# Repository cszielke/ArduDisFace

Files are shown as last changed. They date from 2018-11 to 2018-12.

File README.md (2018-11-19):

# ArduDisFace
An Arduino compatible display interface with I2C, SPI and TTY/RS232 for Arduino and Raspberry PI
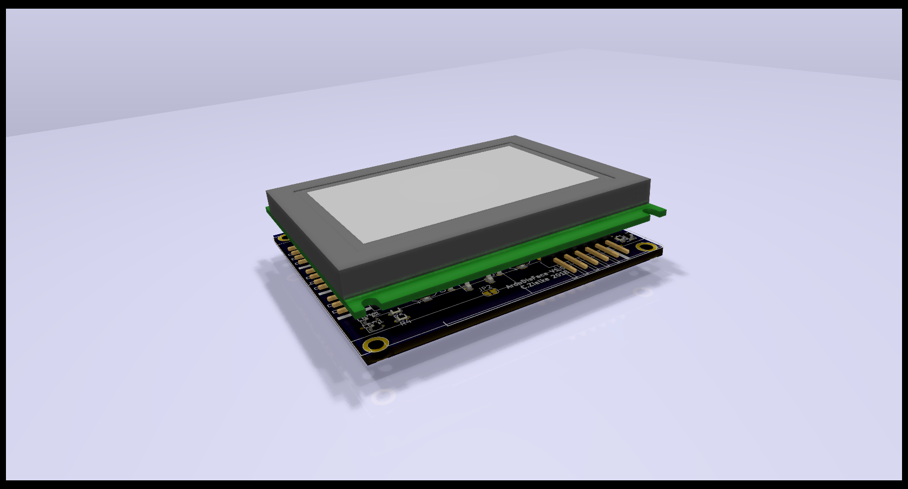
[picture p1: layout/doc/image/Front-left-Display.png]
ArduDisFace with Display


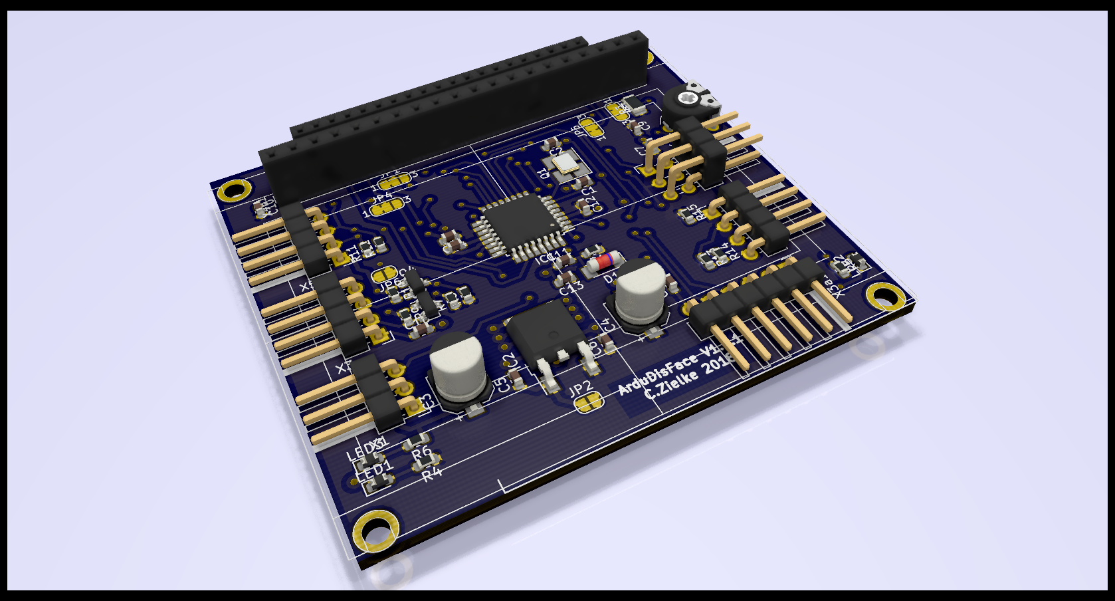
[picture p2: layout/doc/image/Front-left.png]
ArduDisFace board


ArduDisFace scheet

Layout is done in KiCad 5.0.0

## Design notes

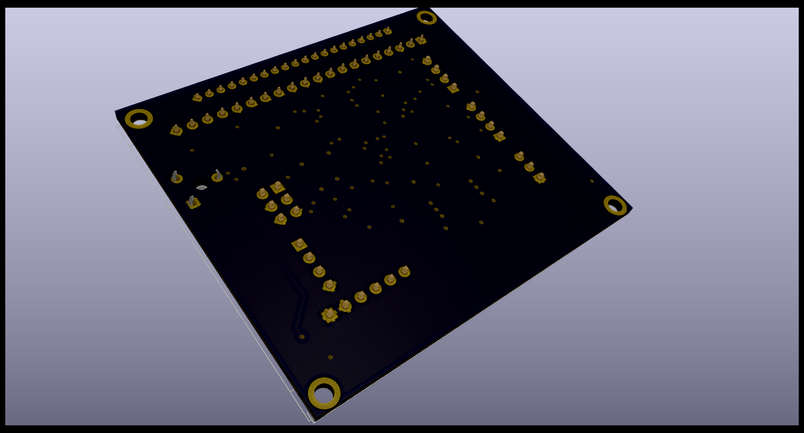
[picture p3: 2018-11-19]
layout/doc/image/Bottom-right.png

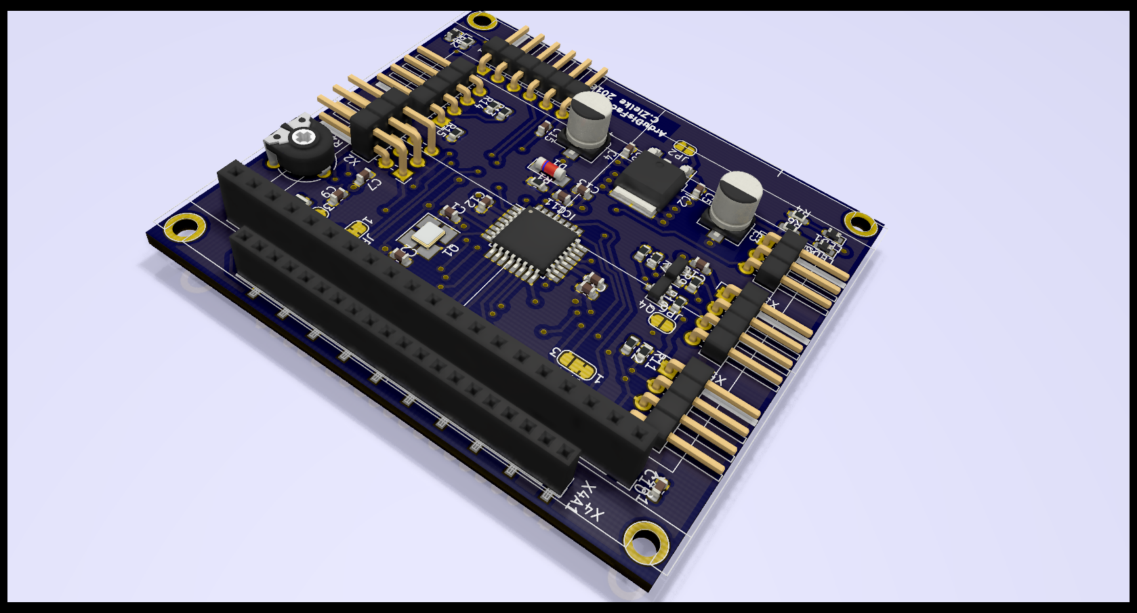
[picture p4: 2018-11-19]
layout/doc/image/Back-left.png

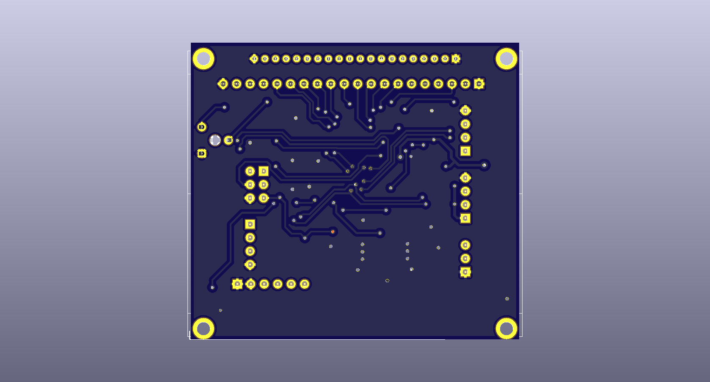
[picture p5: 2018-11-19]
layout/doc/image/bottom.png

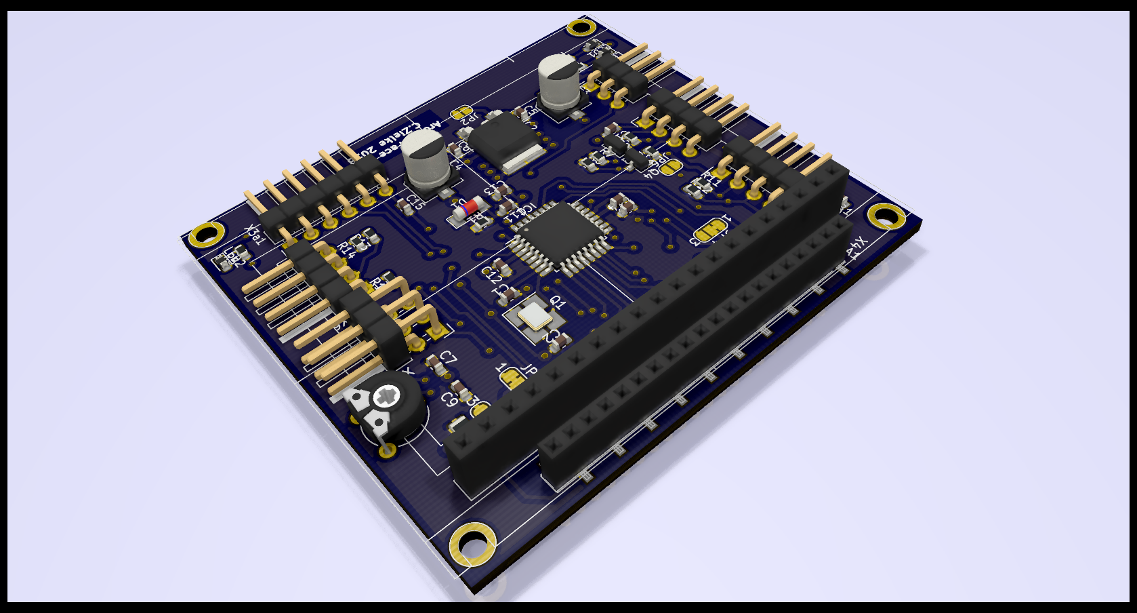
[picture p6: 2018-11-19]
layout/doc/image/Bach-right.png

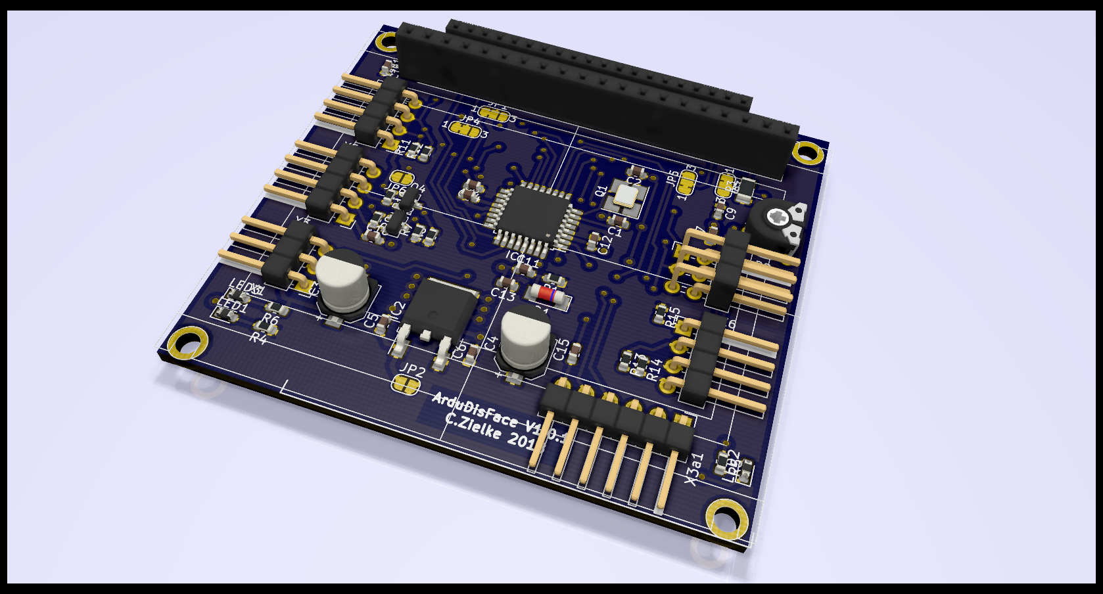
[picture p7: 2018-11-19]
layout/doc/image/Front-right.png

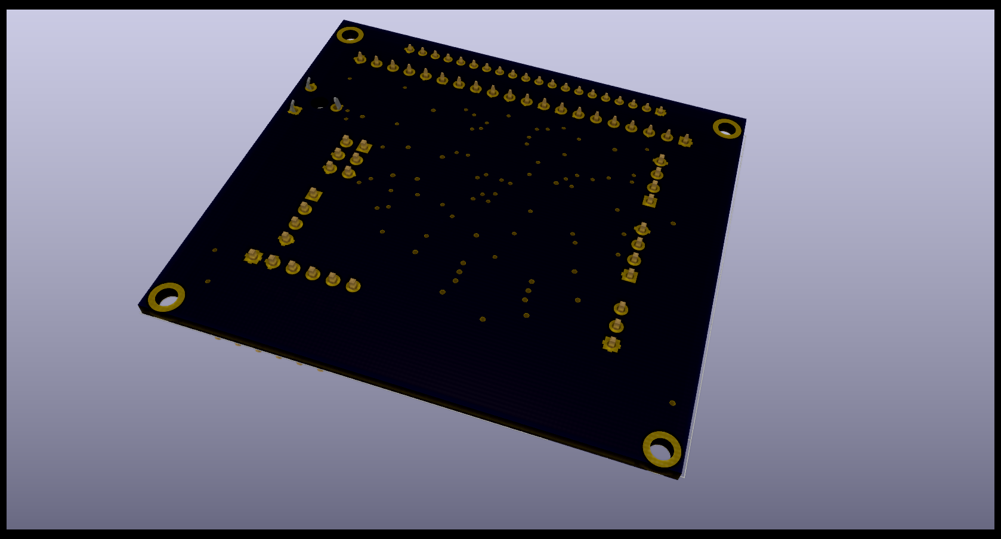
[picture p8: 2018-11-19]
layout/doc/image/Bottom-left.png

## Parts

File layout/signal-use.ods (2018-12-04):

Arduino | Display | SPI | RS232 | I2C | Key analog | Touch
D0 |  |  | RxD
D1 |  |  | TxD
D2 | E
D3 | D/I
D4 | DB4
D5 | DB5
D6 | DB6
D7 | DB7
D8 | DB0
D9 | DB1
D10 | DB2
D11 | DB3 | MOSI
D12 |  | MISO
D13 |  | CLK
A0 | CS0 |  |  |  |  | X+
A1 | CS1 |  |  |  |  | Y+
A2 |  |  |  |  |  | X-
A3 |  |  |  |  |  | Y-
A4 |  |  |  | Dat
A5 |  |  |  | Clk
A6 |  |  |  |  | Ain
A7
VCC | VCC,RST,BK-A | VCC
GND | GND,R/W,BK-K | GND
 | Vo
 | VEE
 | Messure X Pos |  | Messure Y Pos
X+ | Sig |  | H
Y+ | H |  | Sig
X- | Inf. |  | L
Y- | L |  | Inf.

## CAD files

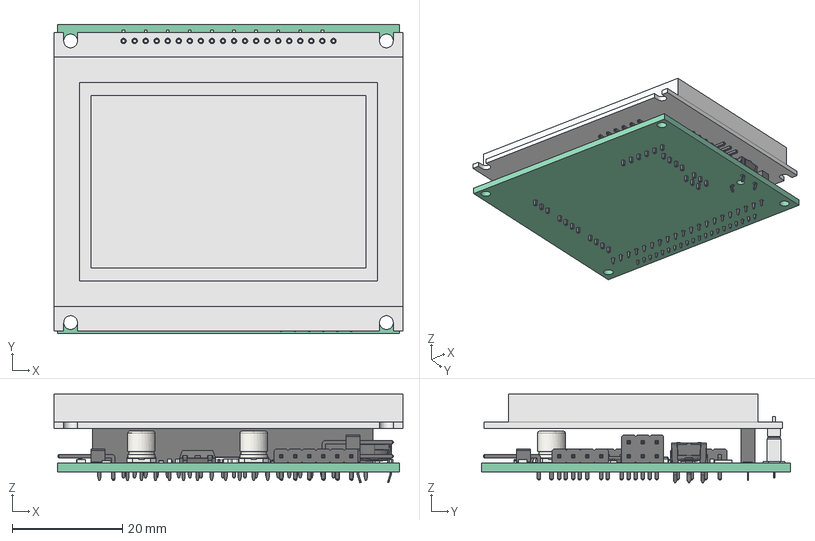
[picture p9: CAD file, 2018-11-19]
layout/cad/3d/ArduDisFace.FCStd
63.2 x 56.0 x 16.0 mm
Pcb
Q1_Crystal_SMD_SeikoEpson_FA238-4pin_3.2x2.5mm_5BDDAC89
C16_C_0603_1608Metric_5BF1AAE5
X6_PinHeader_1x04_P254mm_Horizontal_5BF1C72D
R13_R_0603_1608Metric_5BF1C0FE
R14_R_0603_1608Metric_5BF1C0ED
R15_R_0603_1608Metric_5BF1C0DC
X2_PinHeader_2x03_P254mm_Horizontal_5BE82DCA
R11_R_0603_1608Metric_5BF7230D
R12_R_0603_1608Metric_5BF722FC
R9_R_0603_1608Metric_5BF60786
R10_R_0603_1608Metric_5BF60775
R7_R_0603_1608Metric_5BF606F4
R8_R_0603_1608Metric_5BF606E3
Q2_SOT_23_5BF55F0E
Q4_SOT_23_5BF55EE4
C15_C_0603_1608Metric_5BF352D5
X3a1_PinHeader_1x06_P254mm_Horizontal_5BF2EDBC
C13_C_0603_1608Metric_5BF63ECF
C12_C_0603_1608Metric_5BF63EBE
C14_C_0603_1608Metric_5BF63E2D
C11_C_0603_1608Metric_5BF4F902
X4_MG12064E_5BE92253
X4A1_PinSocket_1x20_P200mm_Vertical_5BF33D64
X4B1_PinSocket_1x20_P254mm_Vertical_5BF33D3C
LED3_D_0603_5BF0806C
R6_R_0603_1608Metric_5BF07E85
R2_Potentiometer_Piher_PT_6_V_Vertical_Hole_5BD7B07F[2]
R3_R_1206_3216Metric_5BD6DC04
C9_C_0603_1608Metric_5BD83F18
C10_C_0603_1608Metric_5BE6C3AB
C1_C_0603_1608Metric_5BD84912
C2_C_0603_1608Metric_5BD84922
C7_C_0603_1608Metric_5BD84932
C8_C_0603_1608Metric_5BD84942
C5_C_0603_1608Metric_5BDD5CB1
C6_C_0603_1608Metric_5BDD5CC1
IC1_TQFP_32_7x7mm_P08mm_5BDD5CD1
IC2_TO_252_2_5BDD5D07
C3_CP_Elec_5x58_5BDD6961
C4_CP_Elec_5x58_5BDD6988
LED1_D_0603_5BDD75B7
R4_R_0603_1608Metric_5BDD75C9
D1_D_MiniMELF_Standard_5BDDAC71
R1_R_0603_1608Metric_5BDDF50A
X3_PinHeader_1x04_P254mm_Horizontal_5BE6259A
X5_PinHeader_1x04_P254mm_Horizontal_5BE625E6
LED2_D_0603_5BEA31C4
R5_R_0603_1608Metric_5BEA3192
X1_PinHeader_1x03_P254mm_Horizontal_5BEDBB2E

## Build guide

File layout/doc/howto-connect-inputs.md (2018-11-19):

# Input variants #
## Using keys for input ##
If you want to connect keys to your display you can do it this way:
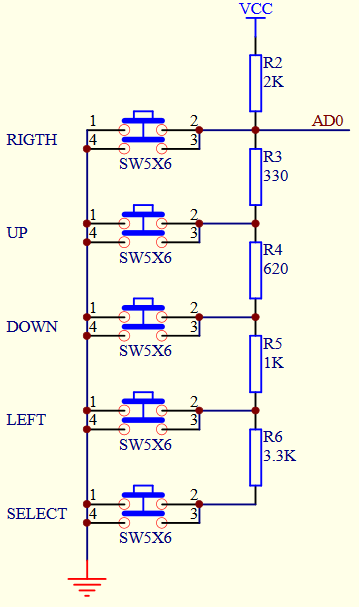
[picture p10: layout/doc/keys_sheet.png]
Keys sheet


Use A6 or A7 instead of A0 for analog reading, witch are located on X6.
<pre>
// read the buttons
int read_LCD_buttons()
{
 adc_key_in = analogRead(0);      // read the value from the sensor 
 // my buttons when read are centered at these valies: 0, 144, 329, 504, 741
 // we add approx 50 to those values and check to see if we are close
 if (adc_key_in > 1000) return btnNONE; // We make this the 1st option for speed reasons since it will be the most likely result
 // For V1.1 us this threshold
 if (adc_key_in < 50)   return btnRIGHT;  
 if (adc_key_in < 250)  return btnUP; 
 if (adc_key_in < 450)  return btnDOWN; 
 if (adc_key_in < 650)  return btnLEFT; 
 if (adc_key_in < 850)  return btnSELECT;  

 return btnNONE;  // when all others fail, return this...
}
</pre>

## Using resistiv touch for input ##
Connector X6 has two analog inputs and can be used to read the signal from a resistive touchscreen.

Mode information here: 
http://ww1.microchip.com/downloads/en/AppNotes/doc8091.pdf 

and her: https://www.sparkfun.com/datasheets/LCD/HOW%20DOES%20IT%20WORK.pdf

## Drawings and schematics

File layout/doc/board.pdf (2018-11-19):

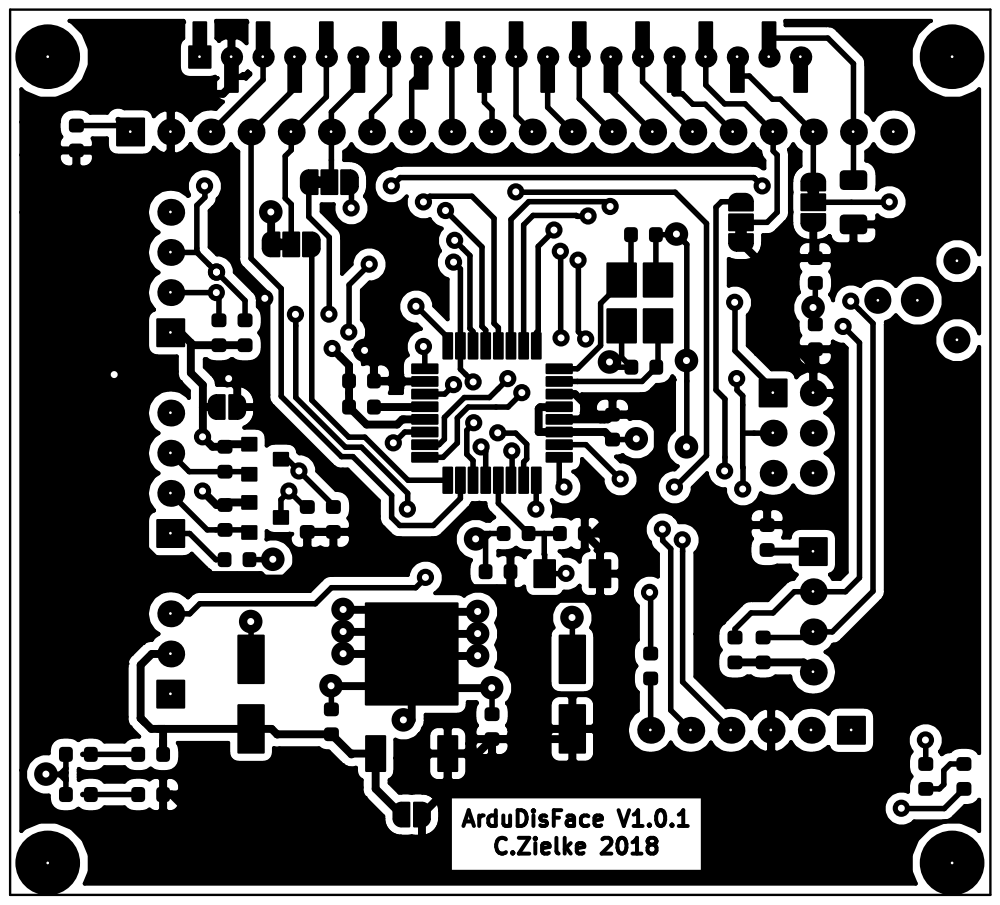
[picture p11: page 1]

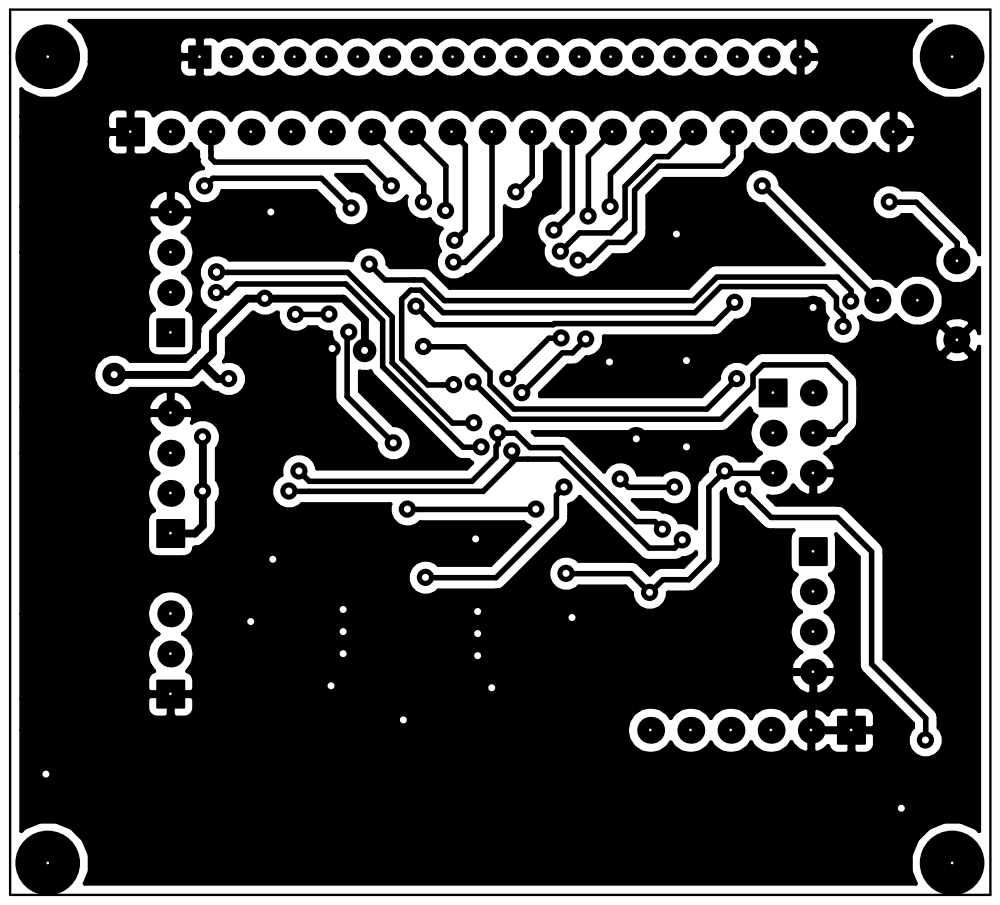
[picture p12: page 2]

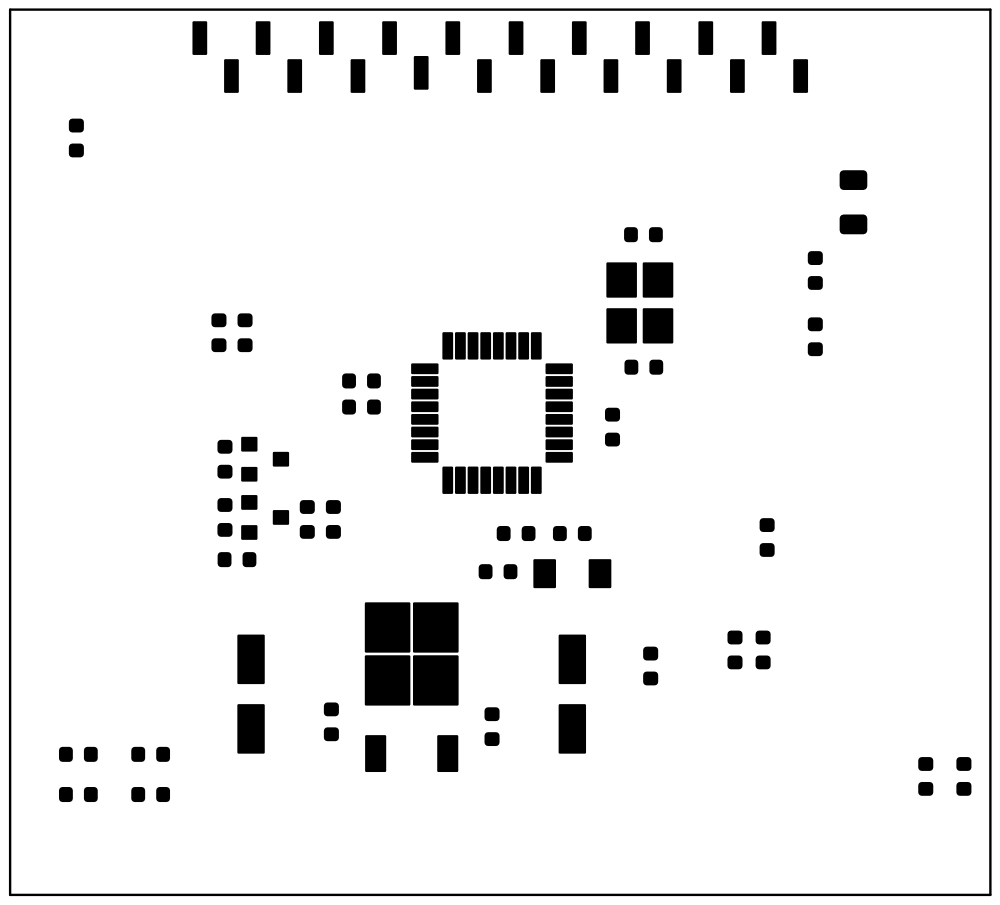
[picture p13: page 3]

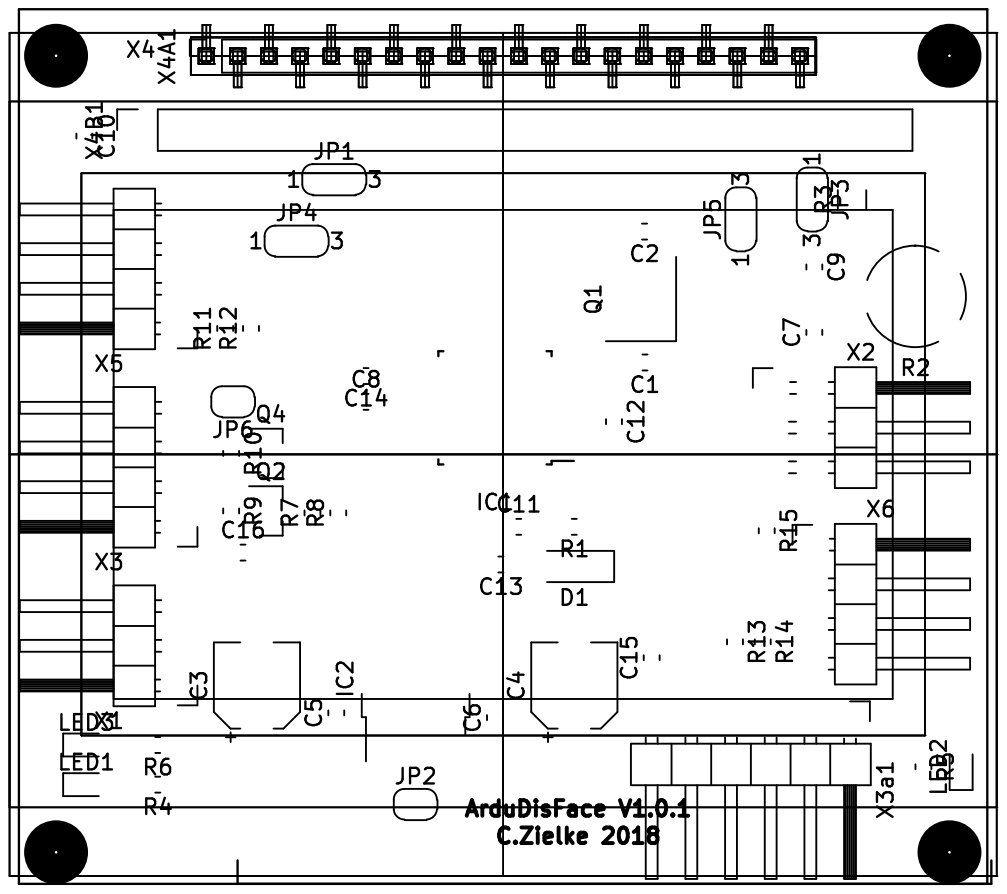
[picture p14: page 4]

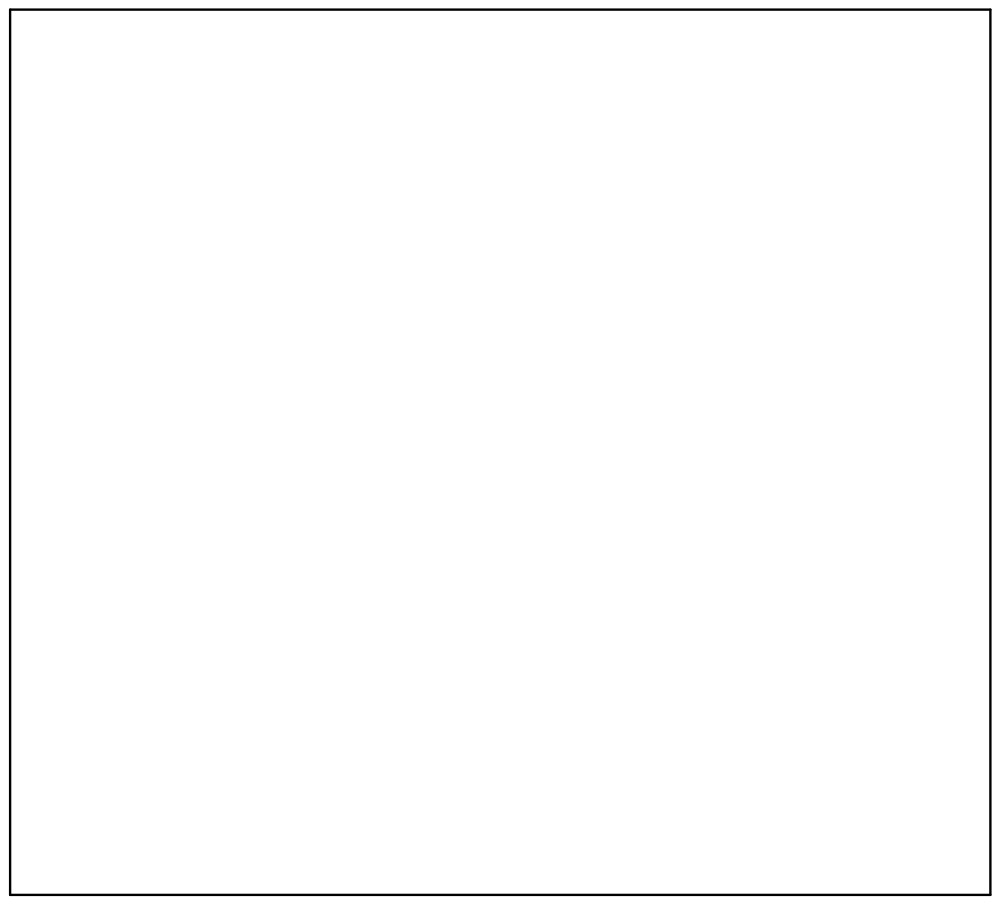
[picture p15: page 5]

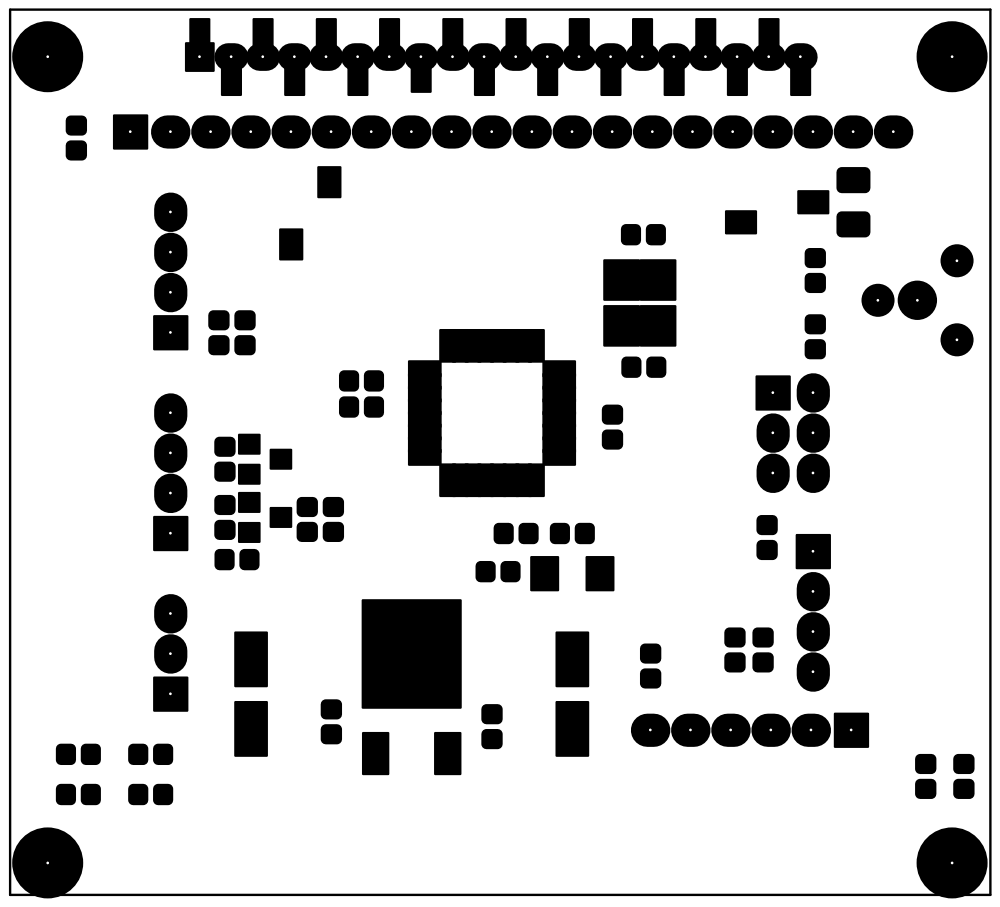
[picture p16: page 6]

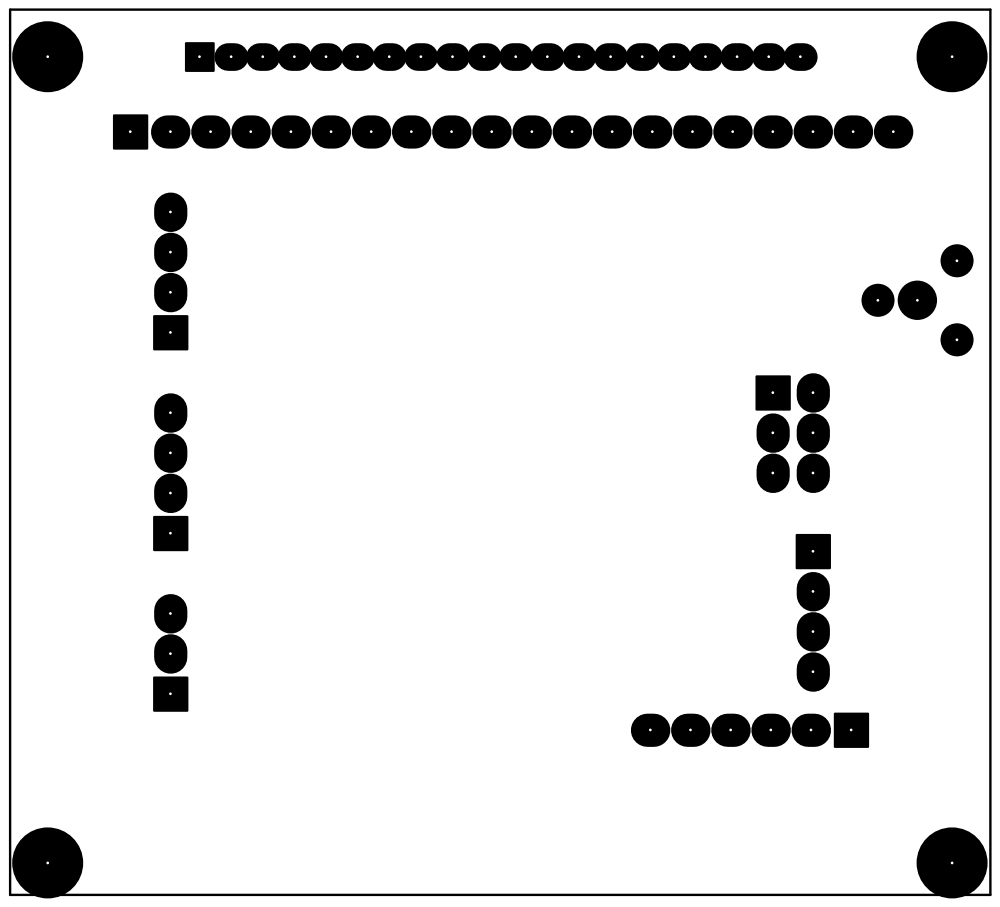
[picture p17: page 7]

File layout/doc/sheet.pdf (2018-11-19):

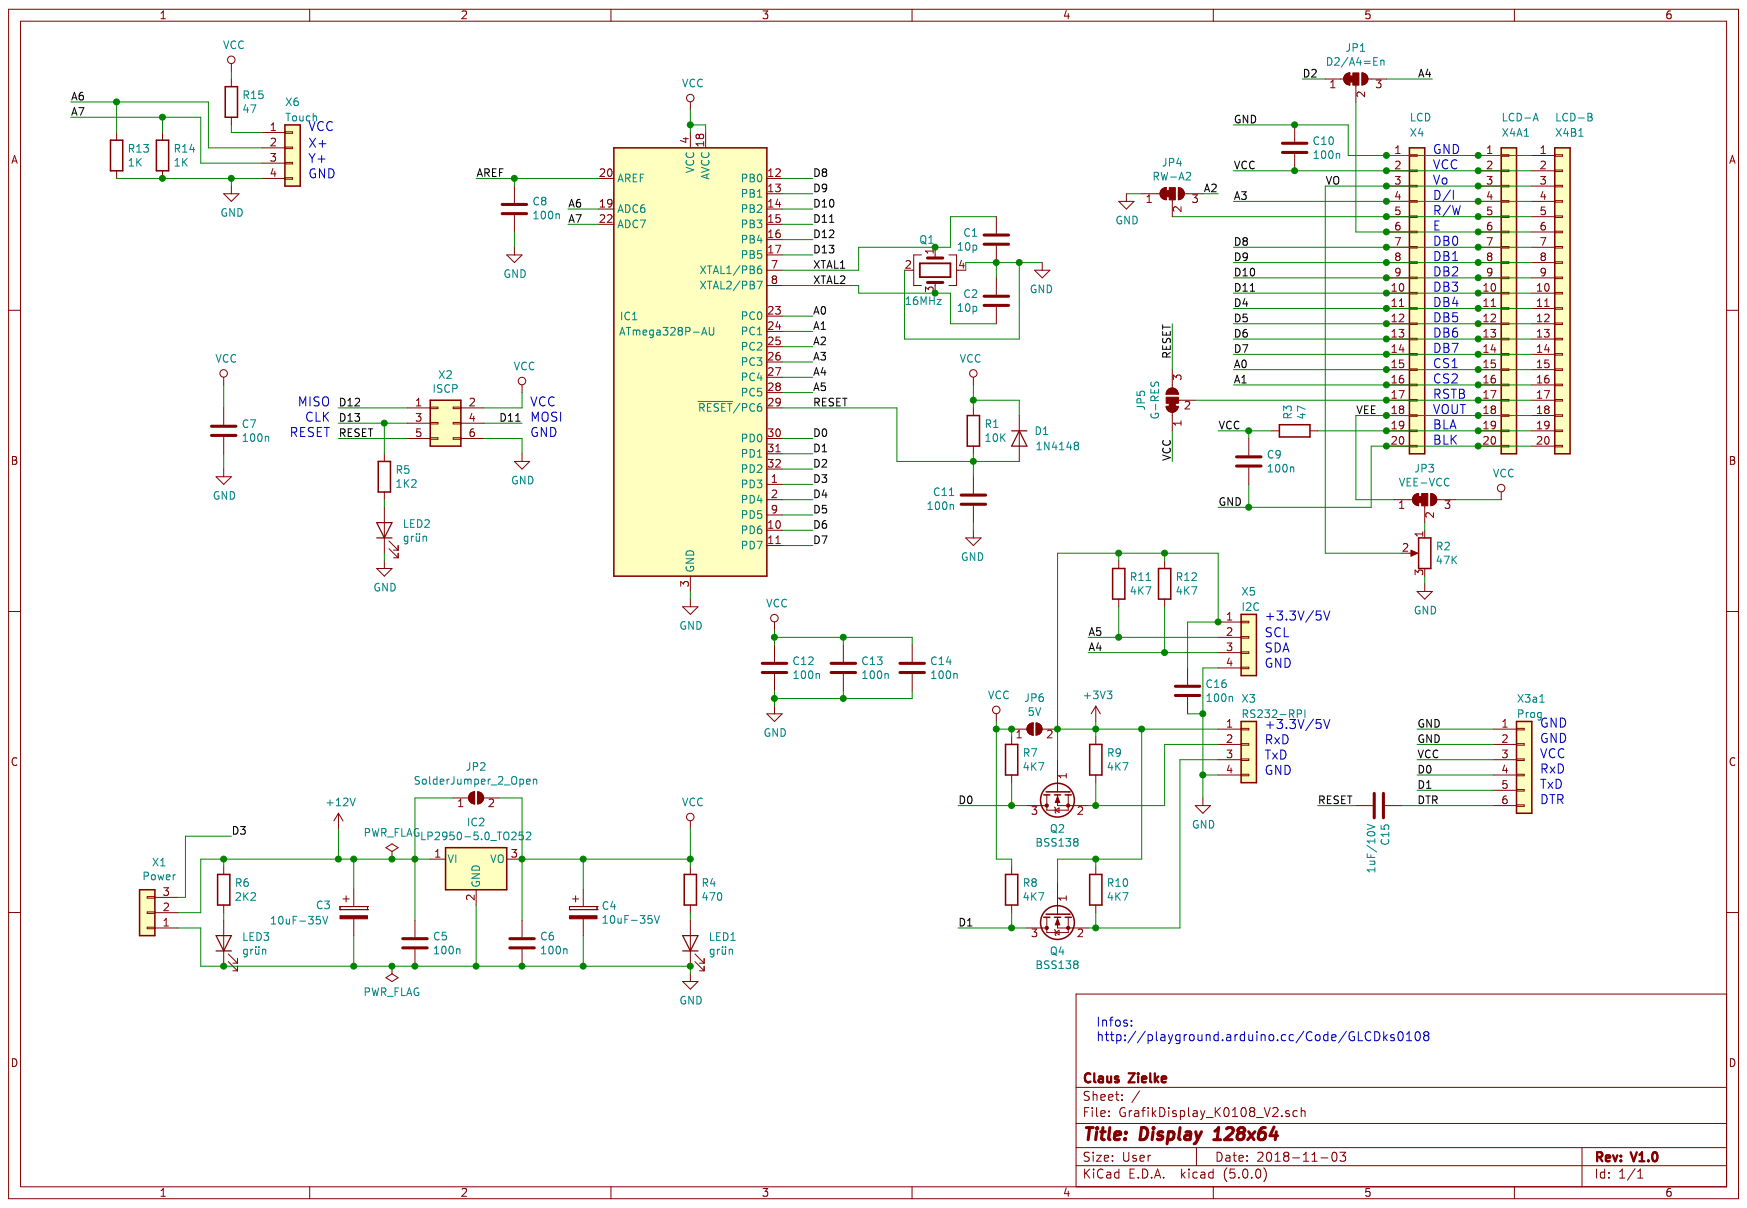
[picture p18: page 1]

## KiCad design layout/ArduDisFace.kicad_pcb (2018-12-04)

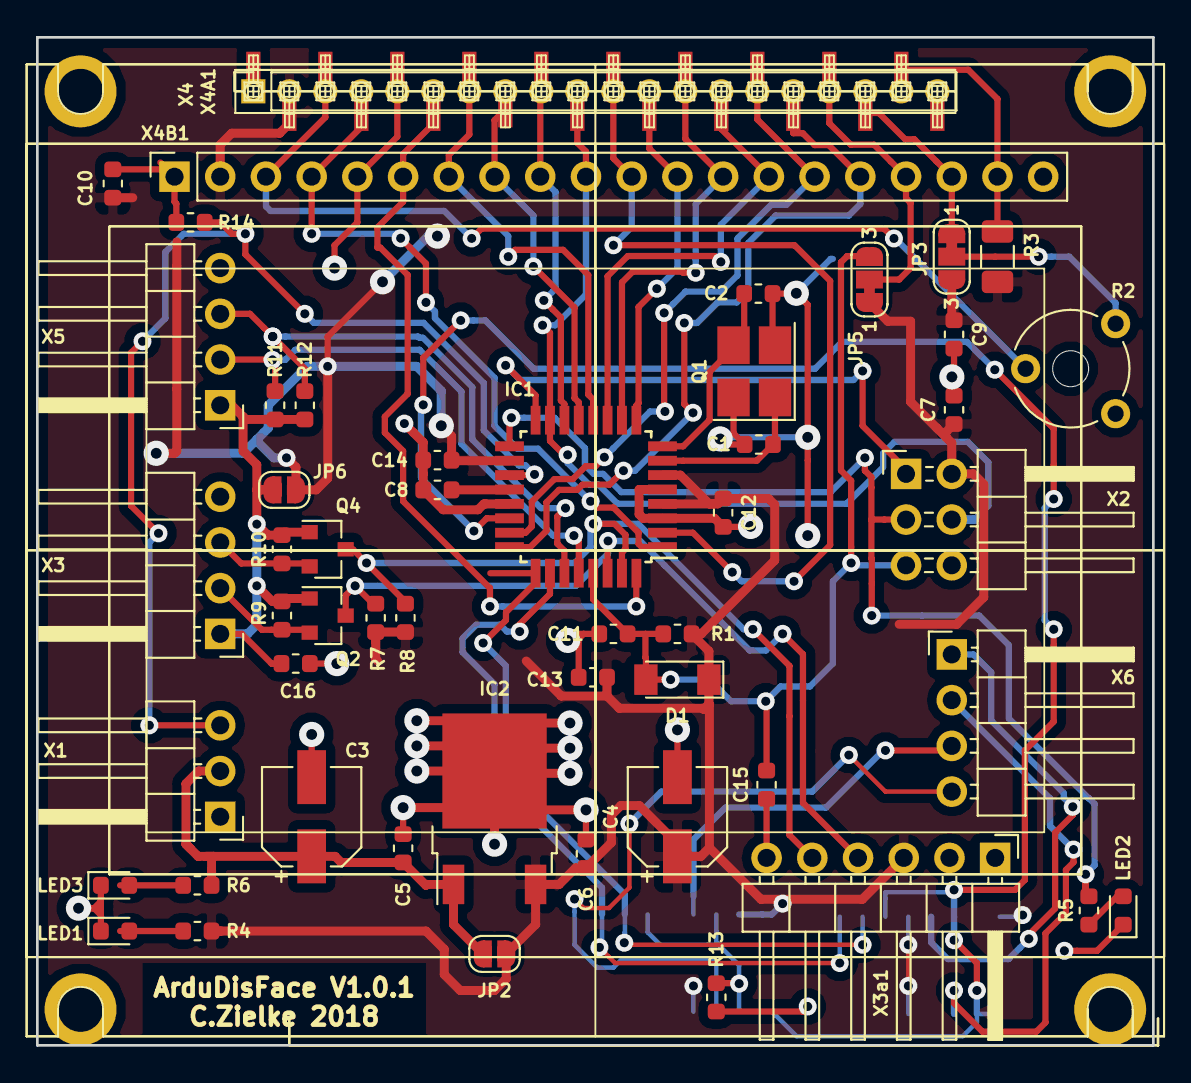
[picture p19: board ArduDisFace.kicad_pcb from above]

Board: 2 copper layers, 62.0 x 56.0 mm, 54 parts (0 on the bottom side), 45 nets.

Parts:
C1, C2: 10p; C_0603_1608Metric
C3, C4: 10uF-35V; CP_Elec_5x5.8
C5, C6, C7, C8, C9, C10, C11, C12, C13, C14, C16: 100n; C_0603_1608Metric
C15: 1uF/10V; C_0603_1608Metric
D1: 1N4148; D_MiniMELF
IC1: ATmega328P-AU; TQFP-32_7x7mm_P0.8mm
IC2: LP2950-5.0_TO252; TO-252-2
JP2: Vin=5V; SolderJumper-2_P1.3mm_Open_RoundedPad1.0x1.5mm
JP3: VEE-VCC; SolderJumper-3_P1.3mm_Bridged12_RoundedPad1.0x1.5mm_NumberL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
JP5: G-RES; SolderJumper-3_P1.3mm_Bridged12_RoundedPad1.0x1.5mm_NumberL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
JP6: 5V; SolderJumper-2_P1.3mm_Open_RoundedPad1.0x1.5mm
LED1: 5V; D_0603_1608Metric
LED2: D13; D_0603_1608Metric
LED3: Vin; D_0603_1608Metric
Q1: 16MHz; Crystal_SMD_3225-4Pin_3.2x2.5mm_HandSoldering
Q2, Q4: BSS138; SOT-23
R1: 10K; R_0603_1608Metric
R2: 47K; Potentiometer_Piher_PT-6-V_Vertical_Hole
R3: 47; R_1206_3216Metric
R4: 470; R_0603_1608Metric
R5: 1K2; R_0603_1608Metric
R6: 2K2; R_0603_1608Metric
R7, R8, R9, R10, R11, R12: 4K7; R_0603_1608Metric
R13, R14: 100K; R_0603_1608Metric
U1, U2: 4052; SOIC-16_3.9x9.9mm_P1.27mm
X1: Power; PinHeader_1x03_P2.54mm_Horizontal
X2: ISCP; PinHeader_2x03_P2.54mm_Horizontal
X3: RS232-RPI; PinHeader_1x04_P2.54mm_Horizontal
X3a1: Prog; PinHeader_1x06_P2.54mm_Horizontal
X4: LCD; MG12064E
X4A1: LCD-A; PinSocket_1x20_P2.00mm_Vertical
X4B1: LCD-B; PinSocket_1x20_P2.54mm_Vertical
X5: I2C; PinHeader_1x04_P2.54mm_Horizontal
X6: Touch; PinHeader_1x04_P2.54mm_Horizontal

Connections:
+3V3: C16.1, JP6.2, Q2.1, Q4.1, R9.1, R10.1, R11.1, R12.1, X3.1, X5.1
+12V: C3.1, C5.1, IC2.1, JP2.1, R6.1, X1.2
/A0: IC1.23, X4.15, X4A1.15, X4B1.15
/A1: IC1.24, X4.16, X4A1.16, X4B1.16
/A2: IC1.25, U1.10, U2.10
/A3: IC1.26, U1.9, U2.9
/A4: IC1.27, R12.2, X5.3
/A5: IC1.28, R11.2, X5.2
/A6: IC1.19, R14.1, X1.3
/A7: IC1.22, R13.1, U1.1, U1.2, U1.11, U1.14, U2.1, U2.2, U2.11, U2.14
/AREF: C8.2, IC1.20
/D0: IC1.30, Q2.3, R7.2, X3a1.4
/D1: IC1.31, Q4.3, R8.2, X3a1.5
/D2: IC1.32, X4.6, X4A1.6, X4B1.6
/D3: IC1.1, X4.4, X4A1.4, X4B1.4
/D4: IC1.2, X4.11, X4A1.11, X4B1.11
/D5: IC1.9, X4.12, X4A1.12, X4B1.12
/D6: IC1.10, X4.13, X4A1.13, X4B1.13
/D7: IC1.11, X4.14, X4A1.14, X4B1.14
/D8: IC1.12, X4.7, X4A1.7, X4B1.7
/D9: IC1.13, X4.8, X4A1.8, X4B1.8
/D10: IC1.14, X4.9, X4A1.9, X4B1.9
/D11: IC1.15, X2.4, X4.10, X4A1.10, X4B1.10
/D12: IC1.16, X2.1
/D13: IC1.17, R5.1, X2.3
/DTR: C15.1, X3a1.6
/RESET: C11.2, C15.2, D1.2, IC1.29, JP5.3, R1.2, X2.5
/VEE: JP3.1, X4.18, X4A1.18, X4B1.18
/VO: R2.2, X4.3, X4A1.3, X4B1.3
/XTAL1: C1.1, IC1.7, Q1.1
/XTAL2: C2.2, IC1.8, Q1.3
GND: C1.2, C2.1, C3.2, C4.2, C5.2, C6.2, C7.2, C8.1, C9.2, C10.1, C11.1, C12.2, C13.2, C14.2, C16.2, IC1.3, IC1.5, IC1.21, IC2.2, LED1.1, LED2.1, LED3.1, Q1.2, Q1.4, R2.3, R13.2, R14.2, U1.5, U1.6, U1.7, U1.8, U1.12, U2.4, U2.6, U2.7, U2.8, U2.15, X1.1, X2.6, X3.4, X3a1.1, X3a1.2, X4.1, X4.5, X4.20, X4A1.1, X4A1.5, X4A1.20, X4B1.1, X4B1.5, X4B1.20, X5.4
unnamed: JP3.2, R2.1
unnamed: JP5.2, X4.17, X4A1.17, X4B1.17
unnamed: LED1.2, R4.2
unnamed: LED2.2, R5.2
unnamed: LED3.2, R6.2
unnamed: Q2.2, R9.2, X3.2
unnamed: Q4.2, R10.2, X3.3
unnamed: R3.2, X4.19, X4A1.19, X4B1.19
unnamed: U1.3, X6.4
unnamed: U1.13, X6.3
unnamed: U2.3, X6.2
unnamed: U2.13, X6.1
VCC: C4.1, C6.1, C7.1, C9.1, C10.2, C12.1, C13.1, C14.1, D1.1, IC1.4, IC1.6, IC1.18, IC2.3, JP2.2, JP3.3, JP5.1, JP6.1, R1.1, R3.1, R4.1, R7.1, R8.1, U1.4, U1.15, U1.16, U2.5, U2.12, U2.16, X2.2, X3a1.3, X4.2, X4A1.2, X4B1.2

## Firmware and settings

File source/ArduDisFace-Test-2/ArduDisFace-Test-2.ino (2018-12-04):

/*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
  * Redistributions in binary form must reproduce the above copyright notice, this 
    list of conditions and the following disclaimer in the documentation and/or other 
    materials provided with the distribution.
  THIS SOFTWARE IS PROVIDED BY THE COPYRIGHT HOLDERS AND 
  CONTRIBUTORS "AS IS" AND ANY EXPRESS OR IMPLIED WARRANTIES, 
  INCLUDING, BUT NOT LIMITED TO, THE IMPLIED WARRANTIES OF 
  MERCHANTABILITY AND FITNESS FOR A PARTICULAR PURPOSE ARE 
  DISCLAIMED. IN NO EVENT SHALL THE COPYRIGHT HOLDER OR 
  CONTRIBUTORS BE LIABLE FOR ANY DIRECT, INDIRECT, INCIDENTAL, 
  SPECIAL, EXEMPLARY, OR CONSEQUENTIAL DAMAGES (INCLUDING, BUT 
  NOT LIMITED TO, PROCUREMENT OF SUBSTITUTE GOODS OR SERVICES; 
  LOSS OF USE, DATA, OR PROFITS; OR BUSINESS INTERRUPTION) HOWEVER 
  CAUSED AND ON ANY THEORY OF LIABILITY, WHETHER IN CONTRACT, 
  STRICT LIABILITY, OR TORT (INCLUDING NEGLIGENCE OR OTHERWISE) 
  ARISING IN ANY WAY OUT OF THE USE OF THIS SOFTWARE, EVEN IF 
  ADVISED OF THE POSSIBILITY OF SUCH DAMAGE.  
*/

#include <Arduino.h>
#include <U8g2lib.h>

#ifdef U8X8_HAVE_HW_SPI
#include <SPI.h>
#endif
#ifdef U8X8_HAVE_HW_I2C
#include <Wire.h>
#endif

/*
  U8glib Example Overview:
    Frame Buffer Examples: clearBuffer/sendBuffer. Fast, but may not work with all Arduino boards because of RAM consumption
    Page Buffer Examples: firstPage/nextPage. Less RAM usage, should work with all Arduino boards.
    U8x8 Text Only Example: No RAM usage, direct communication with display controller. No graphics, 8x8 Text only.
    
  This is a page buffer example.    
*/

//                        rotation, d0, d1, d2, d3, d4, d5, d6, d7, enable, dc, cs0, cs1, cs2         [, reset]
U8G2_KS0108_128X64_1 u8g2(U8G2_R0,   8,  9, 10, 11,  4,  5,  6,  7,      2,  3,  A0,  A1, U8X8_PIN_NONE );

void u8g2_prepare(void) {
  u8g2.setFont(u8g2_font_6x10_tf);
  u8g2.setFontRefHeightExtendedText();
  u8g2.setDrawColor(1);
  u8g2.setFontPosTop();
  u8g2.setFontDirection(0);
}

void u8g2_box_title(uint8_t a) {
  u8g2.drawStr( 10+a*2, 5, "U8g2");
  u8g2.drawStr( 10, 20, "GraphicsTest");
  
  u8g2.drawFrame(0,0,u8g2.getDisplayWidth(),u8g2.getDisplayHeight() );
}

void u8g2_box_frame(uint8_t a) {
  u8g2.drawStr( 0, 0, "drawBox");
  u8g2.drawBox(5,10,20,10);
  u8g2.drawBox(10+a,15,30,7);
  u8g2.drawStr( 0, 30, "drawFrame");
  u8g2.drawFrame(5,10+30,20,10);
  u8g2.drawFrame(10+a,15+30,30,7);
}

void u8g2_disc_circle(uint8_t a) {
  u8g2.drawStr( 0, 0, "drawDisc");
  u8g2.drawDisc(10,18,9);
  u8g2.drawDisc(24+a,16,7);
  u8g2.drawStr( 0, 30, "drawCircle");
  u8g2.drawCircle(10,18+30,9);
  u8g2.drawCircle(24+a,16+30,7);
}

void u8g2_r_frame(uint8_t a) {
  u8g2.drawStr( 0, 0, "drawRFrame/Box");
  u8g2.drawRFrame(5, 10,40,30, a+1);
  u8g2.drawRBox(50, 10,25,40, a+1);
}

void u8g2_string(uint8_t a) {
  u8g2.setFontDirection(0);
  u8g2.drawStr(30+a,31, " 0");
  u8g2.setFontDirection(1);
  u8g2.drawStr(30,31+a, " 90");
  u8g2.setFontDirection(2);
  u8g2.drawStr(30-a,31, " 180");
  u8g2.setFontDirection(3);
  u8g2.drawStr(30,31-a, " 270");
}

void u8g2_line(uint8_t a) {
  u8g2.drawStr( 0, 0, "drawLine");
  u8g2.drawLine(7+a, 10, 40, 55);
  u8g2.drawLine(7+a*2, 10, 60, 55);
  u8g2.drawLine(7+a*3, 10, 80, 55);
  u8g2.drawLine(7+a*4, 10, 100, 55);
}

void u8g2_triangle(uint8_t a) {
  uint16_t offset = a;
  u8g2.drawStr( 0, 0, "drawTriangle");
  u8g2.drawTriangle(14,7, 45,30, 10,40);
  u8g2.drawTriangle(14+offset,7-offset, 45+offset,30-offset, 57+offset,10-offset);
  u8g2.drawTriangle(57+offset*2,10, 45+offset*2,30, 86+offset*2,53);
  u8g2.drawTriangle(10+offset,40+offset, 45+offset,30+offset, 86+offset,53+offset);
}

void u8g2_ascii_1() {
  char s[2] = " ";
  uint8_t x, y;
  u8g2.drawStr( 0, 0, "ASCII page 1");
  for( y = 0; y < 6; y++ ) {
    for( x = 0; x < 16; x++ ) {
      s[0] = y*16 + x + 32;
      u8g2.drawStr(x*7, y*10+10, s);
    }
  }
}

void u8g2_ascii_2() {
  char s[2] = " ";
  uint8_t x, y;
  u8g2.drawStr( 0, 0, "ASCII page 2");
  for( y = 0; y < 6; y++ ) {
    for( x = 0; x < 16; x++ ) {
      s[0] = y*16 + x + 160;
      u8g2.drawStr(x*7, y*10+10, s);
    }
  }
}

void u8g2_extra_page(uint8_t a)
{
  u8g2.drawStr( 0, 0, "Unicode");
  u8g2.setFont(u8g2_font_unifont_t_symbols);
  u8g2.setFontPosTop();
  u8g2.drawUTF8(0, 24, "☀ ☁");
  switch(a) {
    case 0:
    case 1:
    case 2:
    case 3:
      u8g2.drawUTF8(a*3, 36, "☂");
      break;
    case 4:
    case 5:
    case 6:
    case 7:
      u8g2.drawUTF8(a*3, 36, "☔");
      break;
  }
}

void u8g2_xor(uint8_t a) {
  uint8_t i;
  u8g2.drawStr( 0, 0, "XOR");
  u8g2.setFontMode(1);
  u8g2.setDrawColor(2);
  for( i = 0; i < 5; i++)
  {
    u8g2.drawBox(10+i*16, 18 + (i&1)*4, 21,31);
  }
  u8g2.drawStr( 5+a, 19, "XOR XOR XOR XOR");
  u8g2.setDrawColor(0);
  u8g2.drawStr( 5+a, 29, "CLR CLR CLR CLR");
  u8g2.setDrawColor(1);
  u8g2.drawStr( 5+a, 39, "SET SET SET SET");
  u8g2.setFontMode(0);
    
}

#define cross_width 24
#define cross_height 24
static const unsigned char cross_bits[] U8X8_PROGMEM  = {
  0x00, 0x18, 0x00, 0x00, 0x24, 0x00, 0x00, 0x24, 0x00, 0x00, 0x42, 0x00, 
  0x00, 0x42, 0x00, 0x00, 0x42, 0x00, 0x00, 0x81, 0x00, 0x00, 0x81, 0x00, 
  0xC0, 0x00, 0x03, 0x38, 0x3C, 0x1C, 0x06, 0x42, 0x60, 0x01, 0x42, 0x80, 
  0x01, 0x42, 0x80, 0x06, 0x42, 0x60, 0x38, 0x3C, 0x1C, 0xC0, 0x00, 0x03, 
  0x00, 0x81, 0x00, 0x00, 0x81, 0x00, 0x00, 0x42, 0x00, 0x00, 0x42, 0x00, 
  0x00, 0x42, 0x00, 0x00, 0x24, 0x00, 0x00, 0x24, 0x00, 0x00, 0x18, 0x00, };

#define cross_fill_width 24
#define cross_fill_height 24
static const unsigned char cross_fill_bits[] U8X8_PROGMEM  = {
  0x00, 0x00, 0x00, 0x00, 0x00, 0x00, 0x18, 0x00, 0x18, 0x64, 0x00, 0x26, 
  0x84, 0x00, 0x21, 0x08, 0x81, 0x10, 0x08, 0x42, 0x10, 0x10, 0x3C, 0x08, 
  0x20, 0x00, 0x04, 0x40, 0x00, 0x02, 0x80, 0x00, 0x01, 0x80, 0x18, 0x01, 
  0x80, 0x18, 0x01, 0x80, 0x00, 0x01, 0x40, 0x00, 0x02, 0x20, 0x00, 0x04, 
  0x10, 0x3C, 0x08, 0x08, 0x42, 0x10, 0x08, 0x81, 0x10, 0x84, 0x00, 0x21, 
  0x64, 0x00, 0x26, 0x18, 0x00, 0x18, 0x00, 0x00, 0x00, 0x00, 0x00, 0x00, };

#define cross_block_width 14
#define cross_block_height 14
static const unsigned char cross_block_bits[] U8X8_PROGMEM  = {
  0xFF, 0x3F, 0x01, 0x20, 0x01, 0x20, 0x01, 0x20, 0x01, 0x20, 0x01, 0x20, 
  0xC1, 0x20, 0xC1, 0x20, 0x01, 0x20, 0x01, 0x20, 0x01, 0x20, 0x01, 0x20, 
  0x01, 0x20, 0xFF, 0x3F, };

void u8g2_bitmap_overlay(uint8_t a) {
  uint8_t frame_size = 28;

  u8g2.drawStr(0, 0, "Bitmap overlay");

  u8g2.drawStr(0, frame_size + 12, "Solid / transparent");
  u8g2.setBitmapMode(false /* solid */);
  u8g2.drawFrame(0, 10, frame_size, frame_size);
  u8g2.drawXBMP(2, 12, cross_width, cross_height, cross_bits);
  if(a & 4)
    u8g2.drawXBMP(7, 17, cross_block_width, cross_block_height, cross_block_bits);

  u8g2.setBitmapMode(true /* transparent*/);
  u8g2.drawFrame(frame_size + 5, 10, frame_size, frame_size);
  u8g2.drawXBMP(frame_size + 7, 12, cross_width, cross_height, cross_bits);
  if(a & 4)
    u8g2.drawXBMP(frame_size + 12, 17, cross_block_width, cross_block_height, cross_block_bits);
}

void u8g2_bitmap_modes(uint8_t transparent) {
  const uint8_t frame_size = 24;

  u8g2.drawBox(0, frame_size * 0.5, frame_size * 5, frame_size);
  u8g2.drawStr(frame_size * 0.5, 50, "Black");
  u8g2.drawStr(frame_size * 2, 50, "White");
  u8g2.drawStr(frame_size * 3.5, 50, "XOR");
  
  if(!transparent) {
    u8g2.setBitmapMode(false /* solid */);
    u8g2.drawStr(0, 0, "Solid bitmap");
  } else {
    u8g2.setBitmapMode(true /* transparent*/);
    u8g2.drawStr(0, 0, "Transparent bitmap");
  }
  u8g2.setDrawColor(0);// Black
  u8g2.drawXBMP(frame_size * 0.5, 24, cross_width, cross_height, cross_bits);
  u8g2.setDrawColor(1); // White
  u8g2.drawXBMP(frame_size * 2, 24, cross_width, cross_height, cross_bits);
  u8g2.setDrawColor(2); // XOR
  u8g2.drawXBMP(frame_size * 3.5, 24, cross_width, cross_height, cross_bits);
}

uint8_t draw_state = 0;

void draw(void) {
  u8g2_prepare();
  switch(draw_state >> 3) {
    case 0: u8g2_box_title(draw_state&7); break;
    case 1: u8g2_box_frame(draw_state&7); break;
    case 2: u8g2_disc_circle(draw_state&7); break;
    case 3: u8g2_r_frame(draw_state&7); break;
    case 4: u8g2_string(draw_state&7); break;
    case 5: u8g2_line(draw_state&7); break;
    case 6: u8g2_triangle(draw_state&7); break;
    case 7: u8g2_ascii_1(); break;
    case 8: u8g2_ascii_2(); break;
    case 9: u8g2_extra_page(draw_state&7); break;
    case 10: u8g2_xor(draw_state&7); break;
    case 11: u8g2_bitmap_modes(0); break;
    case 12: u8g2_bitmap_modes(1); break;
    case 13: u8g2_bitmap_overlay(draw_state&7); break;
  }
}


void setup(void) {
  u8g2.begin();
  //u8g2.setFlipMode(0);
}

void loop(void) {
  // picture loop  
  u8g2.firstPage();  
  do {
    draw();
  } while( u8g2.nextPage() );
  
  // increase the state
  draw_state++;
  if ( draw_state >= 14*8 )
    draw_state = 0;

  // delay between each page
  delay(150);

}

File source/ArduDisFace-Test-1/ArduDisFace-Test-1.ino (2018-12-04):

#include <Arduino.h>
#include <U8g2lib.h>

//                        rotation, d0, d1, d2, d3, d4, d5, d6, d7, enable, dc, cs0, cs1, cs2          [, reset]
U8G2_KS0108_128X64_F u8g2(U8G2_R0,   8,  9, 10, 11,  4,  5,  6,  7,      2, 3,  A0,  A1, U8X8_PIN_NONE );


void setup() {
  // put your setup code here, to run once:
 u8g2.begin();
 pinMode(13,OUTPUT);
}

void loop() {
  
  u8g2.firstPage();
  do {
    u8g2.setFont(u8g2_font_ncenB14_tr);
    u8g2.drawStr(0,20,"Hello World!");
  } while ( u8g2.nextPage() );
  digitalWrite(13,0);
  delay(1000);
  digitalWrite(13,1);
}

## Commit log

2018-11-19 Initial check in
    [ArduDisFace.FCStd, ArduDisFace.kicad_pcb, ArduDisFace.sch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]
2018-12-04 Touch interface with only one ADC input. Usin D3 for direction input
    [ArduDisFace.kicad_pcb, ArduDisFace.sch, signal-use.ods]

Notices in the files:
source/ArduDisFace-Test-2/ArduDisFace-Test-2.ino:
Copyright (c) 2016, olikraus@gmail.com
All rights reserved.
